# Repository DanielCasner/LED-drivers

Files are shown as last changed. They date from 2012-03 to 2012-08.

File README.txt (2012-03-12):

This repository contains source files for hardware software and simulation for various LED drivers initially created by Daniel Casner, www.danielcasner.org daniel@danielcasner.org

See LICENSE file for details on the licenses pertaining to various files.
Hardware source files are compatible with EAGLE 6.0 http://www.cadsoftusa.com/
Simulation source files are compatible with free LTSpice from Linear Technology http://www.linear.com/ltspice
There is no relationship nor implied endorcement between the author of this work and the above software tools.

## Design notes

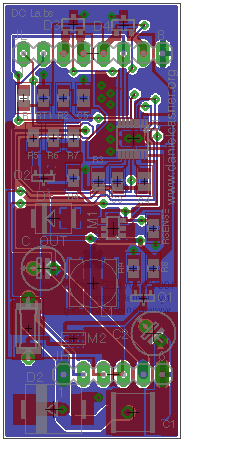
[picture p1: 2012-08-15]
hardware/buck_100v_brd.png

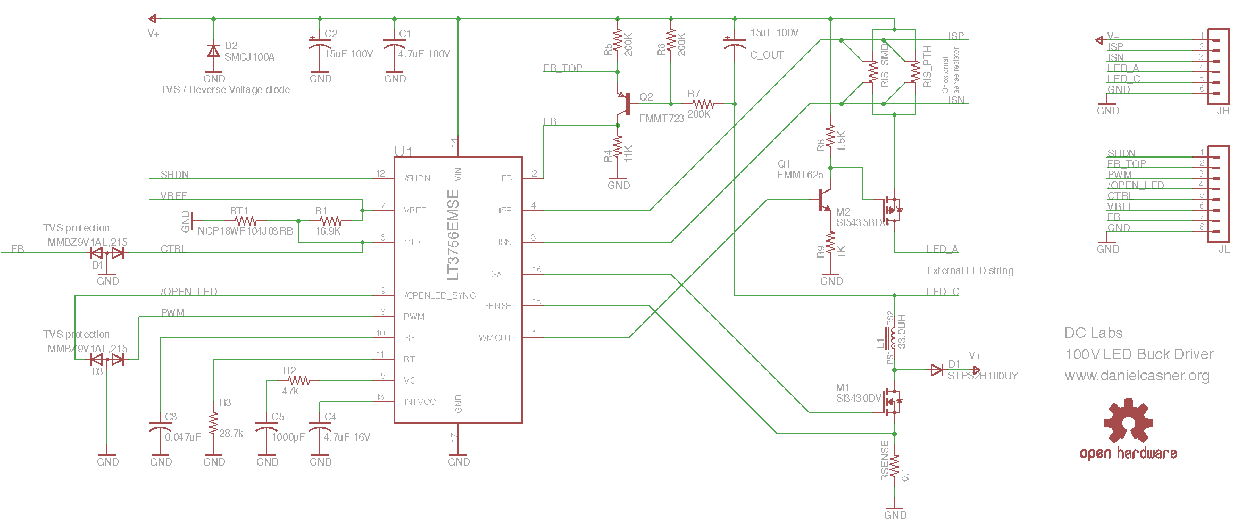
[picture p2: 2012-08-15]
hardware/buck_100v_sch.png

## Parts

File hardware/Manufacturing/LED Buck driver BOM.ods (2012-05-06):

Qty | Parts | Value | Device | Unique Part # | Cost 1 | Cost 1000
1 | L1 | 33.0UH | ASPI-0612FS | ASPI-0612FS-330M-T2 | $0.51 | $0.37
1 | C3 | 0.05uF | C-USC0805 | C0805C473K5RACTU | $0.12 | $0.02
1 | C4 | 4.7uF 100V | C-USC0805 | C2012Y5V1C475Z/1.25 | $0.30 | $0.04
1 | C5 | 1000pF | C-USC0805 | 500R15W102KV4T | $0.04 | $0.01
1 | C1 | 4.7uF 100V | C-USC2220K | C5750X7R2A475M | $2.05 | $1.40
2 | C2, C6 | 15uF 100V | CPOL-USE2,5-6E | UHE2A150MED
2 | D3, D4 | MMBZ9V1AL,215 | DIODE-2CA|ACSOT23 |  | $0.25
1 | D1 | STPS2H100UY | DIODE-SMB |  | $0.61 | $0.22
1 | D2 | SMCJ100A | DIODE-SMC |  | $0.52 | $0.26
1 | Q1 | FMMT625 | FMMT625 |  | $0.70 | $0.24
1 | Q2 | FMMT723 | FMMT723
1 | U1 | LT3756EMSE | LT3756EMSE | LT3756EMSE-2 | $6.38 | $3.64
1 | R10 | 0.1 | R-US_R0805 | MCR10EZHFLR100 | $0.26 | $0.05
1 | R8 | 1.5K | R-US_R0805 | RC0805JR-071K5L | $0.02 | $0.00
1 | R9 | 1K | R-US_R0805 | RC0805JR-071KL
1 | R4 | 11K | R-US_R0805 | RC0805FR-0711KL |  | $0.01
1 | R1 | 16.9K | R-US_R0805 | RC0805FR-0716K9L |  | $0.01
1 | R3 | 28.7k | R-US_R0805 | RC0805FR-0728K7L |  | $0.01
1 | R2 | 47k | R-US_R0805 | RC0805FR-0747K5L |  | $0.01
3 | R5, R6, R7 | 200K | R-US_R0805 | RC0805FR-07200KL |  | $0.01
1 | RT1 | NCP18WF104J03RB | R-US_R0805 |  | $0.22 | $0.11
1 | M1 | SI3430DV | SI3430DV | SI3430DV-T1-E3 | $1.00 | $0.43
1 | M2 | SI5435BDC | SI5435BDC | SI5435BDC-T1-GE3 | $1.10 | $0.48
 |  |  |  | Totals
1 | JH, JL |  |  | 68000-236HLF

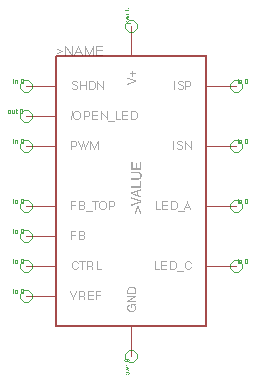
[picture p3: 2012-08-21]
hardware/100V buck component.png

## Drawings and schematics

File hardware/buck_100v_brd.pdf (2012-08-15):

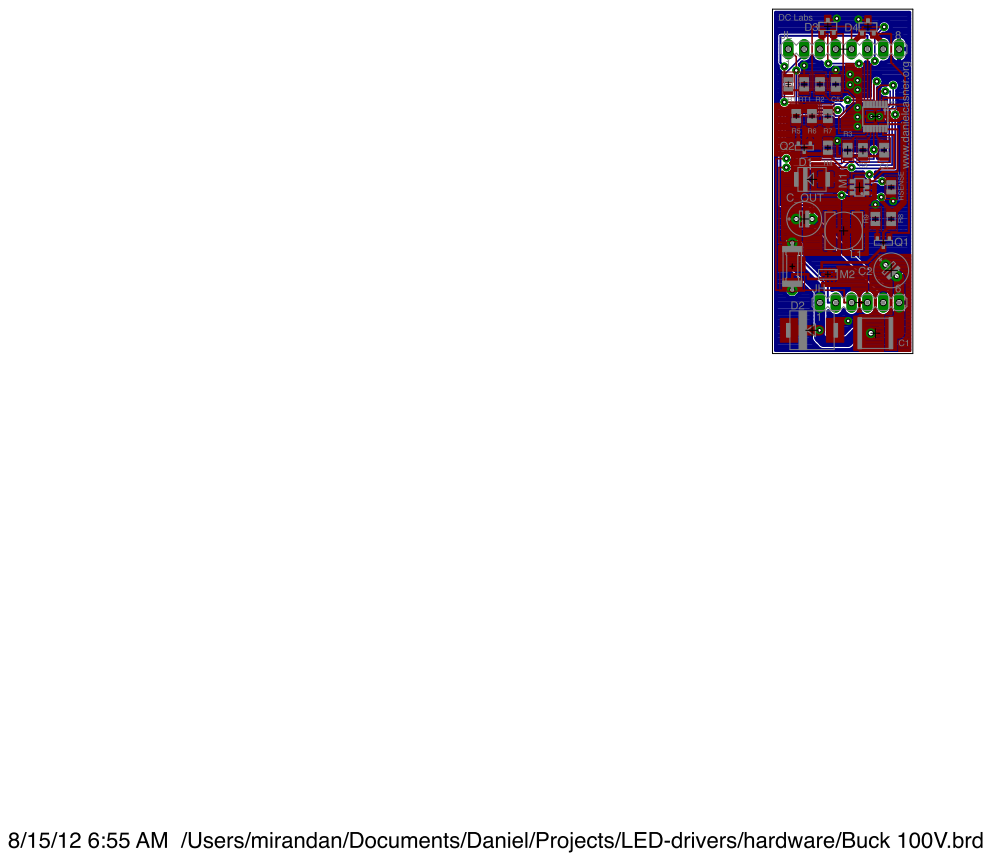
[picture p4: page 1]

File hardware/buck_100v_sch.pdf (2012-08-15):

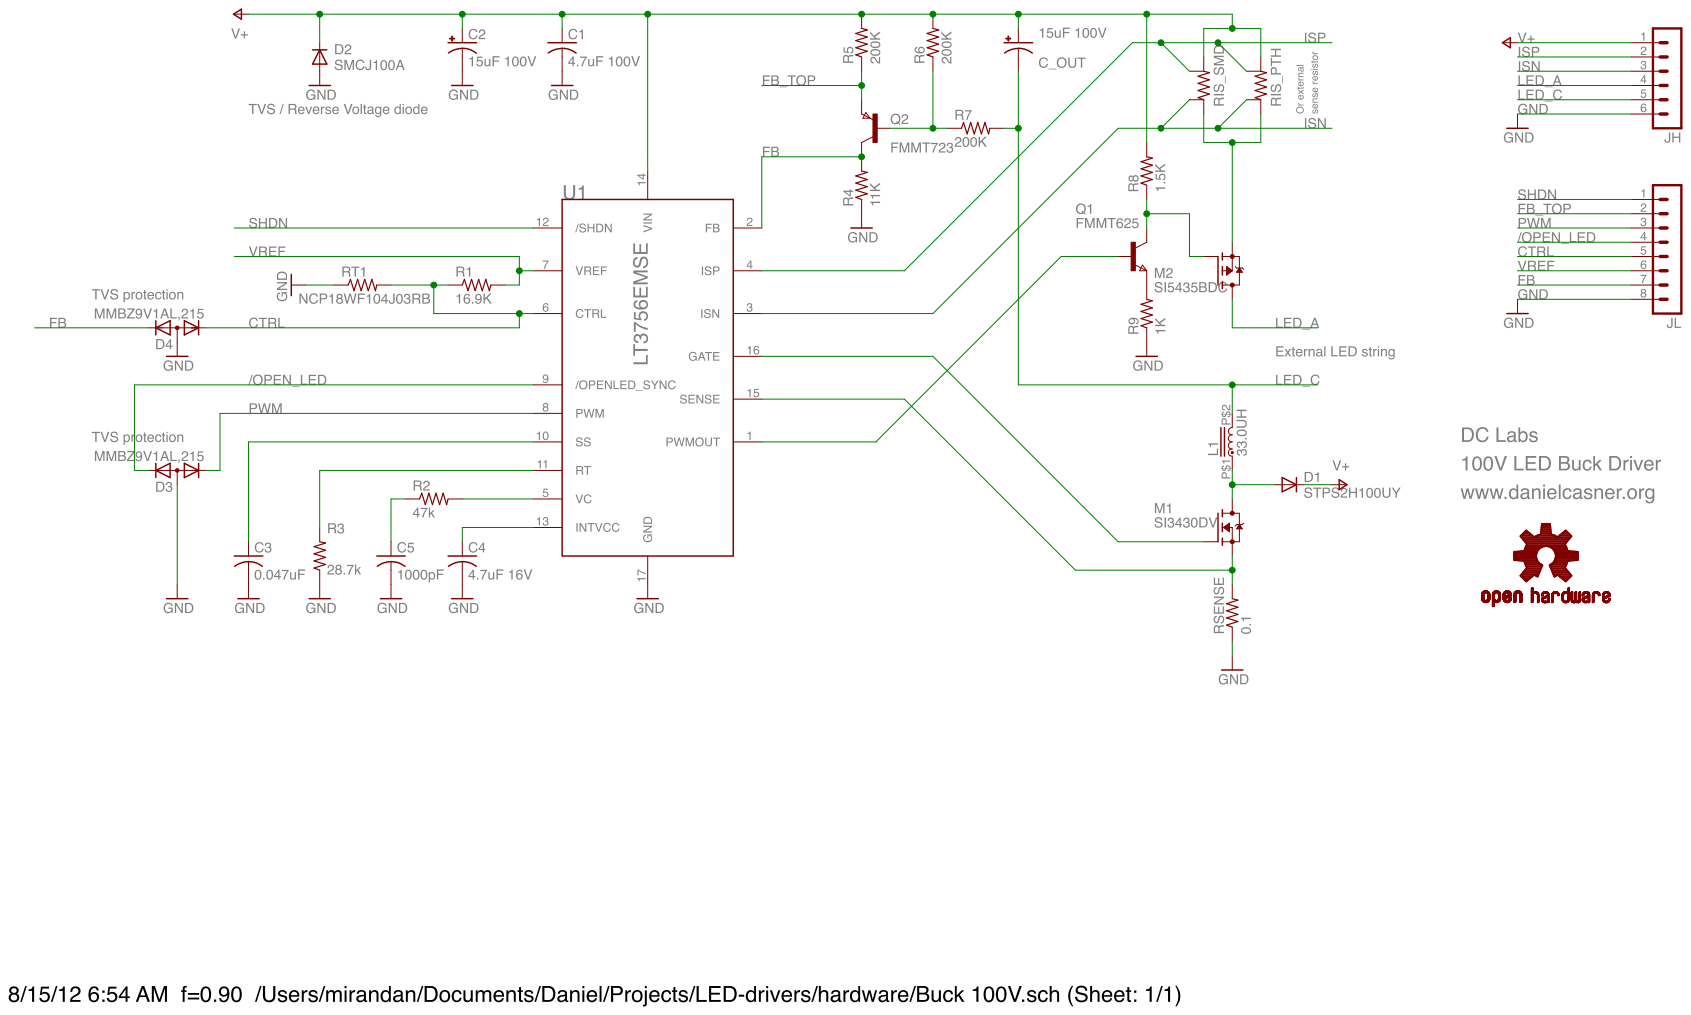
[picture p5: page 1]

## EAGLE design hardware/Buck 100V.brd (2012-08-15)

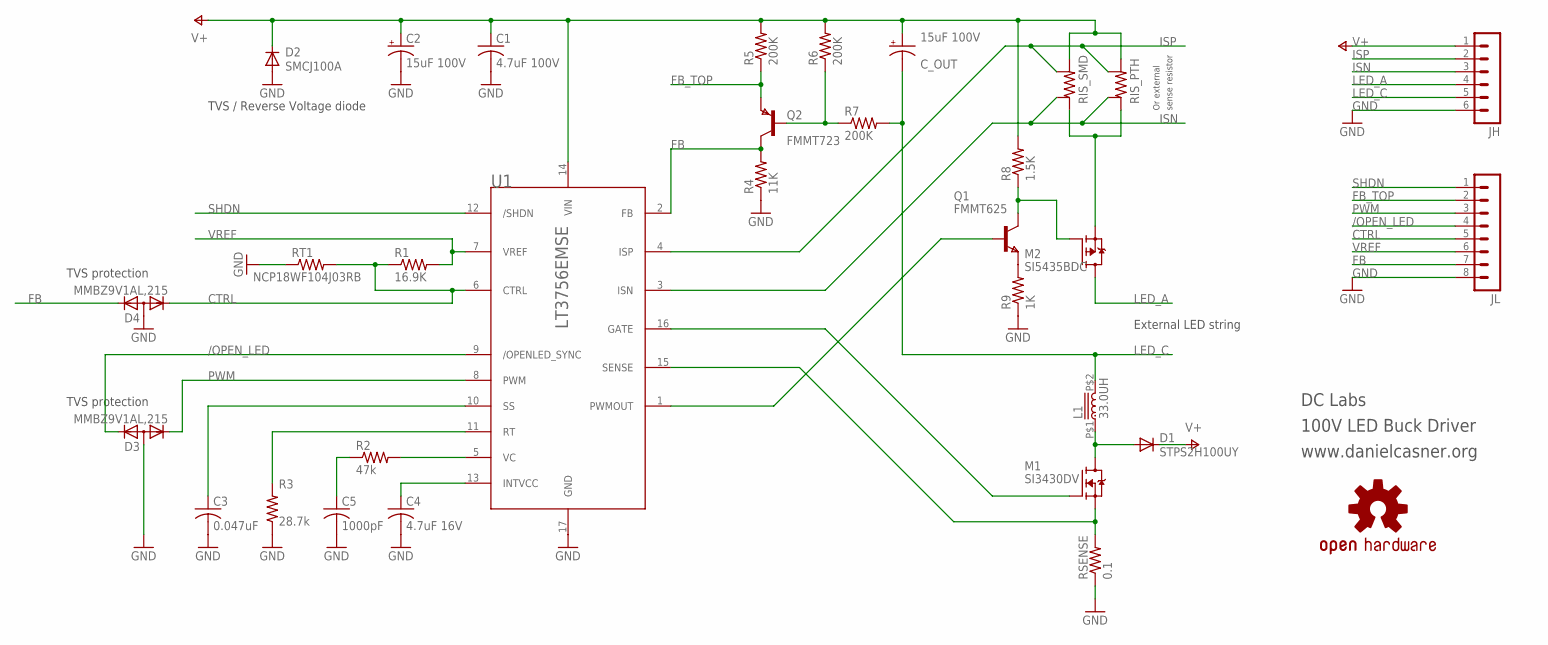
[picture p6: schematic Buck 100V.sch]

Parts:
C1: 4.7uF 100V; C2220K
C2: 15uF 100V; E2,5-6E
C3: 0.047uF; C0805
C4: 4.7uF 16V; C0805
C5: 1000pF; C0805
C_OUT: 15uF 100V; E2,5-6E
D1: STPS2H100UY; SMB
D2: SMCJ100A; SMC
D3, D4: MMBZ9V1AL,215; SOT23
JH: MA06-1
JL: MA08-1
L1: 33.0UH; ASPI-0612FS
M1: SI3430DV; SSOT6
M2: SI5435BDC; 1206-8CHIP-FET
Q1: FMMT625; SOT-23
Q2: FMMT723; SOT-23
R1: 16.9K; R0805
R2: 47k; R0805
R3: 28.7k; R0805
R4: 11K; R0805
R5, R6, R7: 200K; R0805
R8: 1.5K; R0805
R9: 1K; R0805
RIS_PTH: R-KELVIN0204/7; 0204/7-KELVIN
RIS_SMD: R-KELVINR2512; R2512_KELVIN
RSENSE: 0.1; R0805
RT1: NCP18WF104J03RB; R0805
U1: LT3756EMSE; MSOP16EXP
U$1: OSHW-LOGOS; OSHW-LOGO-S

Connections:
/OPEN_LED: D3.2 (K2), JL.4, U1.9 (/OPENLED_SYNC)
CTRL: D4.1 (K1), JL.5, R1.1, RT1.2, U1.6 (CTRL)
FB: D4.2 (K2), JL.7, Q2.1 (C), R4.2, U1.2 (FB)
FB_TOP: JL.2, Q2.2 (E), R5.1
GND: C1.2, C2.-, C3.2, C4.2, C5.2, D2.A, D3.3 (A), D4.3 (A), JH.6, JL.8, R3.1, R4.1, R9.1, RSENSE.1, RT1.1, U1.17 (GND)
ISN: JH.3, RIS_PTH.1S, RIS_SMD.1S, U1.3 (ISN)
ISP: JH.2, RIS_PTH.2S, RIS_SMD.2S, U1.4 (ISP)
LED_A: JH.4, M2.1 (D), M2.2 (D), M2.3 (D), M2.6 (D), M2.7 (D), M2.8 (D)
LED_C: C_OUT.-, JH.5, L1.P$2 (2), R7.2
unnamed: C3.1, U1.10 (SS)
unnamed: C4.1, U1.13 (INTVCC)
unnamed: R2.2, U1.5 (VC)
unnamed: C5.1, R2.1
unnamed: R3.2, U1.11 (RT)
unnamed: M2.5 (S), RIS_PTH.1, RIS_SMD.1
unnamed: Q2.3 (B), R6.1, R7.1
unnamed: M2.4 (G), Q1.1 (C), R8.1
unnamed: Q1.2 (E), R9.2
unnamed: Q1.3 (B), U1.1 (PWMOUT)
unnamed: M1.3 (G), U1.16 (GATE)
unnamed: M1.4 (S), RSENSE.2, U1.15 (SENSE)
N_BUCK: D1.A, L1.P$1 (1), M1.1 (D), M1.2 (D), M1.5 (D), M1.6 (D)
PWM: D3.1 (K1), JL.3, U1.8 (PWM)
SHDN: JL.1, U1.12 (/SHDN)
V+: C1.1, C2.+, C_OUT.+, D1.C, D2.C, JH.1, R5.2, R6.2, R8.2, RIS_PTH.2, RIS_SMD.2, U1.14 (VIN)
VREF: JL.6, R1.2, U1.7 (VREF)

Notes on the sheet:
TVS / Reverse Voltage diode
TVS protection
Or external
sense resistor
External LED string
DC Labs
100V LED Buck Driver
www.danielcasner.org

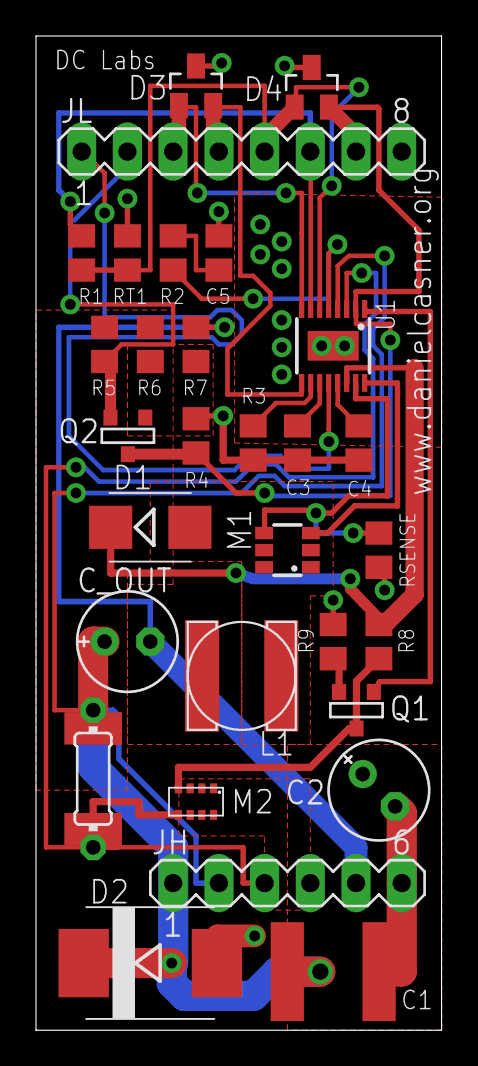
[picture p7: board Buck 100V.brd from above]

Board: 2 copper layers, 22.5 x 55.2 mm, 32 parts (1 on the bottom side), 26 nets.

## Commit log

2012-03-03 Checkpoint, added EAGLE Library and start buck schematic.
    [Buck 100V.sch]
2012-03-12 More progress on schematic.
    [Buck 100V.sch]
2012-03-13 More work on Buck schematic. Now it just needs the schotkey diode, headers and double checking.
    [Buck 100V.sch]
2012-03-14 Add schottky diode. Change resistors and caps to 0805 for hand solderability. Still need headers and checking before starting layout. Also need reverse protection diode and possibly est protection co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
    [Buck 100V.sch]
2012-03-15 Finished schematic (needs a careful double check). Added LTSpice output files to .gitignore.
    [Buck 100V.sch]
2012-03-15 Beautify and correct the schematic. Made the two headers different sizes so that it is harder to put the part in backwards. Next step is to run and confirm BOM.
    [Buck 100V.sch]
2012-03-17 Minor fixes.
    [Buck 100V.sch]
2012-03-17 Add BOM spread sheet for Buck driver.
    [LED Buck driver BOM.ods]
2012-03-17 Add board created from schematic. No placement done yet.
    [Buck 100V.sch]
2012-03-21 Create kelvin terminated versions of current sense resistors and adjust schematic accordingly. Signals on the buck headers are now more clearly named. The kelvin terminated resistors WILL cause DRC e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
    [Buck 100V.brd, Buck 100V.sch]
2012-03-24 Very rough initial board layout. Can now safely say that the board will be smaller than 2 inches by 3 inches.
    [Buck 100V.brd, Buck 100V.sch]
2012-04-07 Some progress on layout and routing.
    [Buck 100V.brd, Buck 100V.sch]
2012-04-14 Progress on layout and routing.
    [Buck 100V.brd]
2012-04-28 Checkpoint before trying autorouting again.
    [Buck 100V.brd]
2012-04-28 VICTORY! Over place and route.
    [Buck 100V.brd, Buck 100V.sch]
2012-04-29 Smash size and position part names for screen printing.
    [Buck 100V.brd]
2012-04-29 Add DRC and CAM scripts, some modification to go with new DRC.
    [Buck 100V.brd]
2012-05-02 Better routing for ESD protection. Fix airwires.
    [Buck 100V.brd]
2012-05-02 Fine tune routing after reviewing gerbers.
    [Buck 100V.brd]
2012-05-05 Add BatchPCB design rules and cam script. Make some adjustments to the layout for batchPCB rule check.
    [Buck 100V.brd]
2012-05-06 Modify BatchPCB cam file to my tastes and their updated requirements. Add more silk screen labeling to the board. Update the BOM.
    [Buck 100V.brd, LED Buck driver BOM.ods]
2012-05-10 Working on a library part to represent the led driver board on other boards.
2012-07-08 Finish library part of LED 100V buck driver for use in other boards.
2012-08-15 Missed from previous commit.
    [Buck 100V.brd, Buck 100V.sch]
2012-08-15 Added manufacturing files from 2012-05 build.
    Moved BOM into manufacturing folder.
    [LED Buck driver BOM.ods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]
2012-08-21 Add figure of 100V LED driver component.

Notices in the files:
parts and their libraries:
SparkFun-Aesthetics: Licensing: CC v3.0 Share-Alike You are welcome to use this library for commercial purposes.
